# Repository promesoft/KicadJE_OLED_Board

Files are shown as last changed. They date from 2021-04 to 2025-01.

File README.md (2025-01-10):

# KicadJE_OLED_Board
uP Boards that uses I2C SSD1306 for OLED Display faceplate

# Purpose
uProcessor board in eurorack units with an SSD1306 OLED display, two rotary dials/pots, two audio inputs, two cv inputs and two outputs. Must match the Faceplate - KicadJE_OLED_Face.
## Board 1 - ATMega32A
Adjustment:  
2 x Encoder  

CV Input:  
2 x ADC AC/DC couple with optional level adj to match 0-5V ADC

Gate or Input Audio:  
2 x ADC AC/DC couple with optional level adj to match 0-5V ADC

Output CV:  
2 x PWM output through 3 pole active LP  
+-10v

Programming Interface:  
ISP  
Serial  

# Status - Initiated
## Initial 
| Stage  | Detail | Status |
| --- | --- | --- |
| create material  | sch | OK
| | pcb | OK
| | gerber | OK
| production |  |  OK
|  | produced  | OK
|  | delivered | OK
## Preliminary validation
| Test  | Detail | Status |
| --- | --- | --- |
| Initial Inspection | | ok |
| Mechanical Inspection | needs longer pins to OLED | ok |
| Initial Technical Test | Board 1 |  |
| Initial Product Test | Board1 |  |

## Secondary validation
| Test  | Detail | Status |
| --- | --- |--- |
| Product Test | 1 | |
| Quality | 1 | |
| Long Term Product Test |  |  |
| Power Draw |  | 

## Errata
### Errata - 

## Issues and Notes
### 

# Pictures

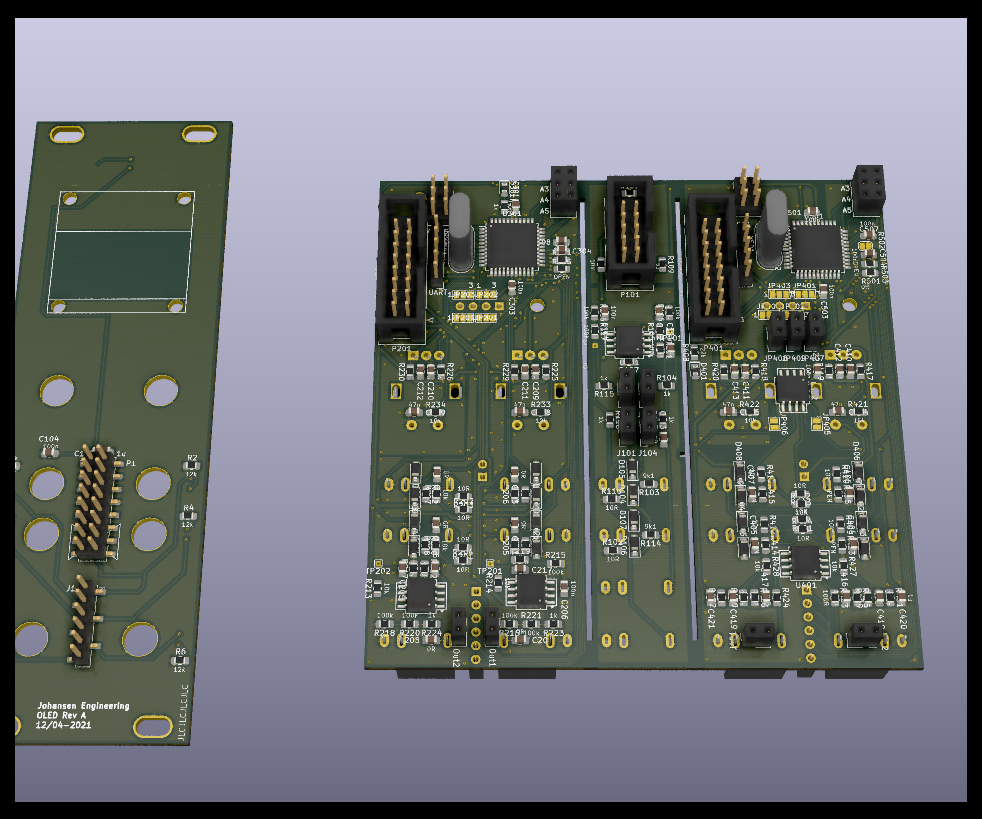
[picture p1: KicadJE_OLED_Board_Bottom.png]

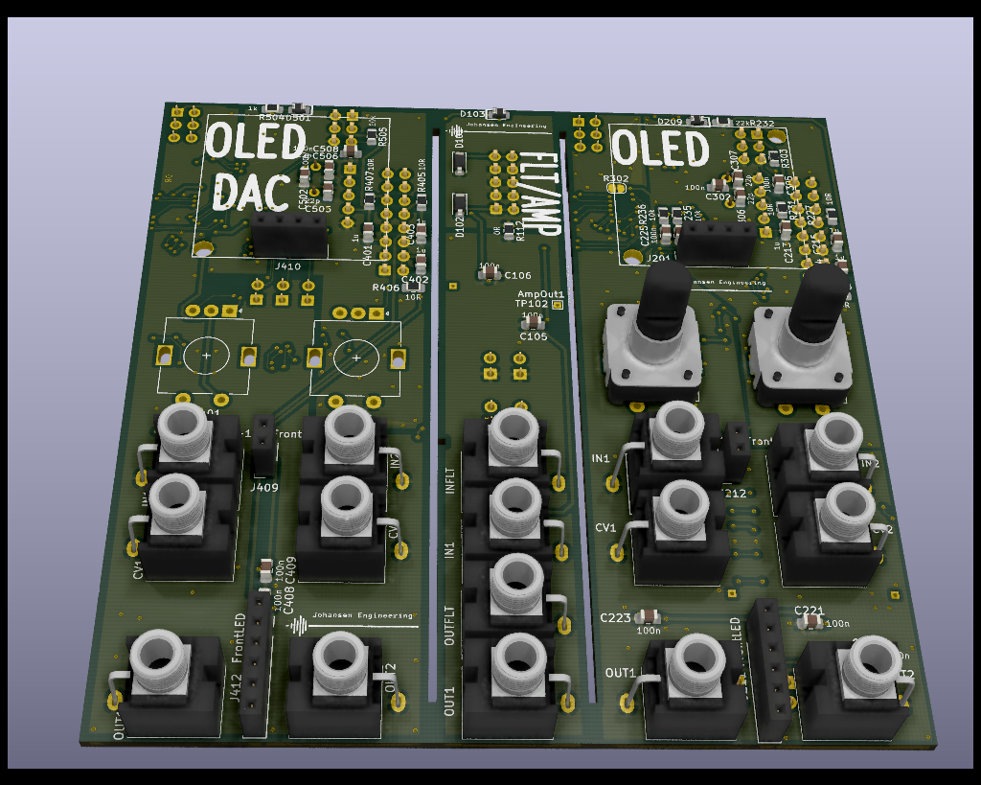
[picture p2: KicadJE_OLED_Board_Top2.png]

# Schematic
## Sch 1
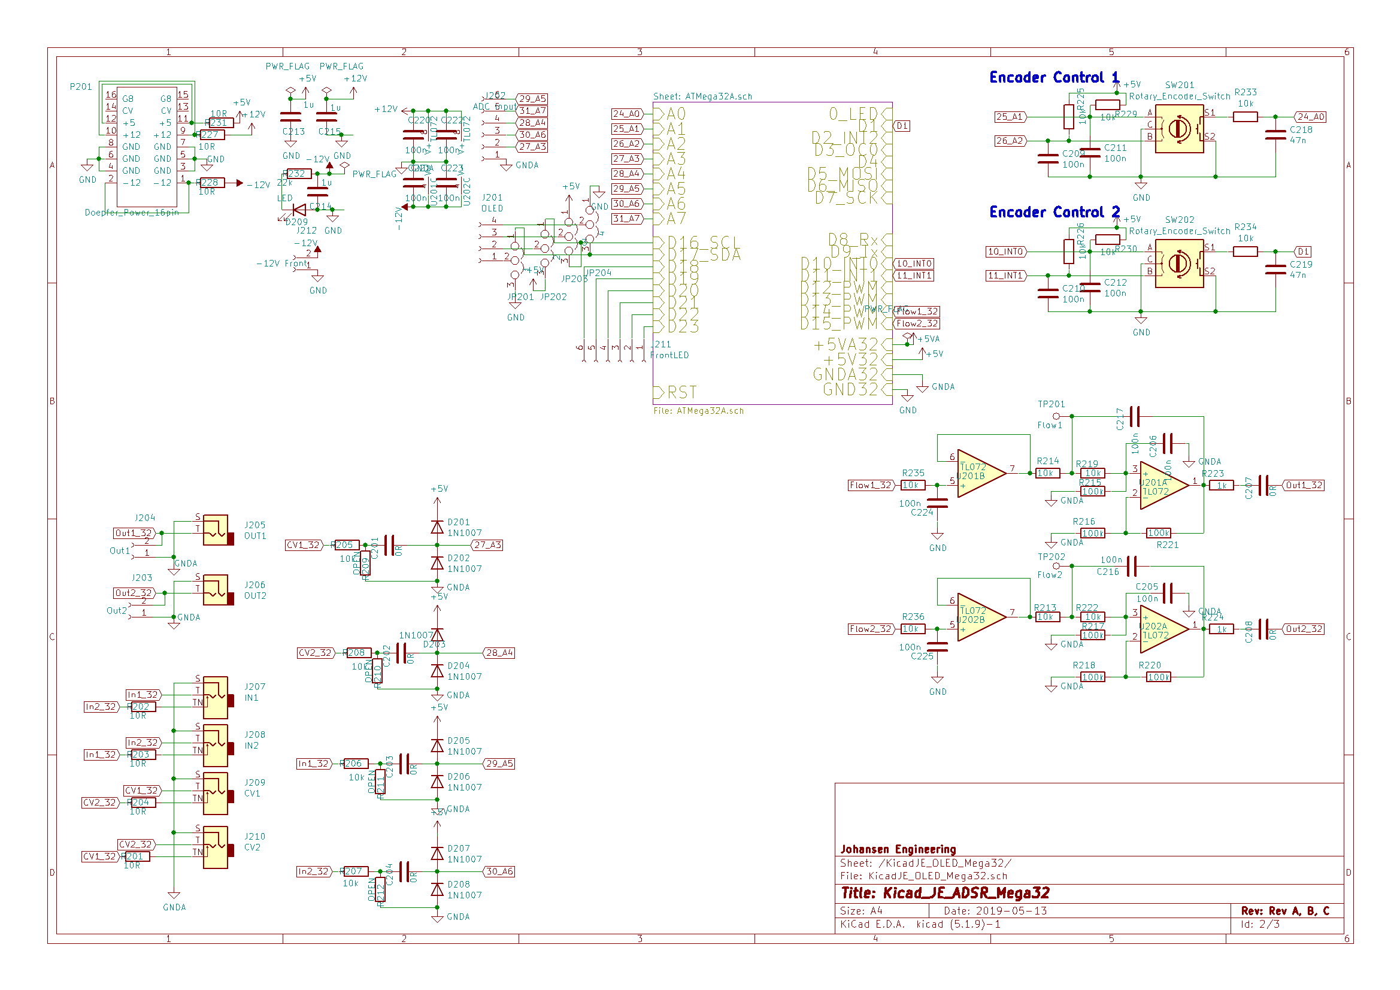
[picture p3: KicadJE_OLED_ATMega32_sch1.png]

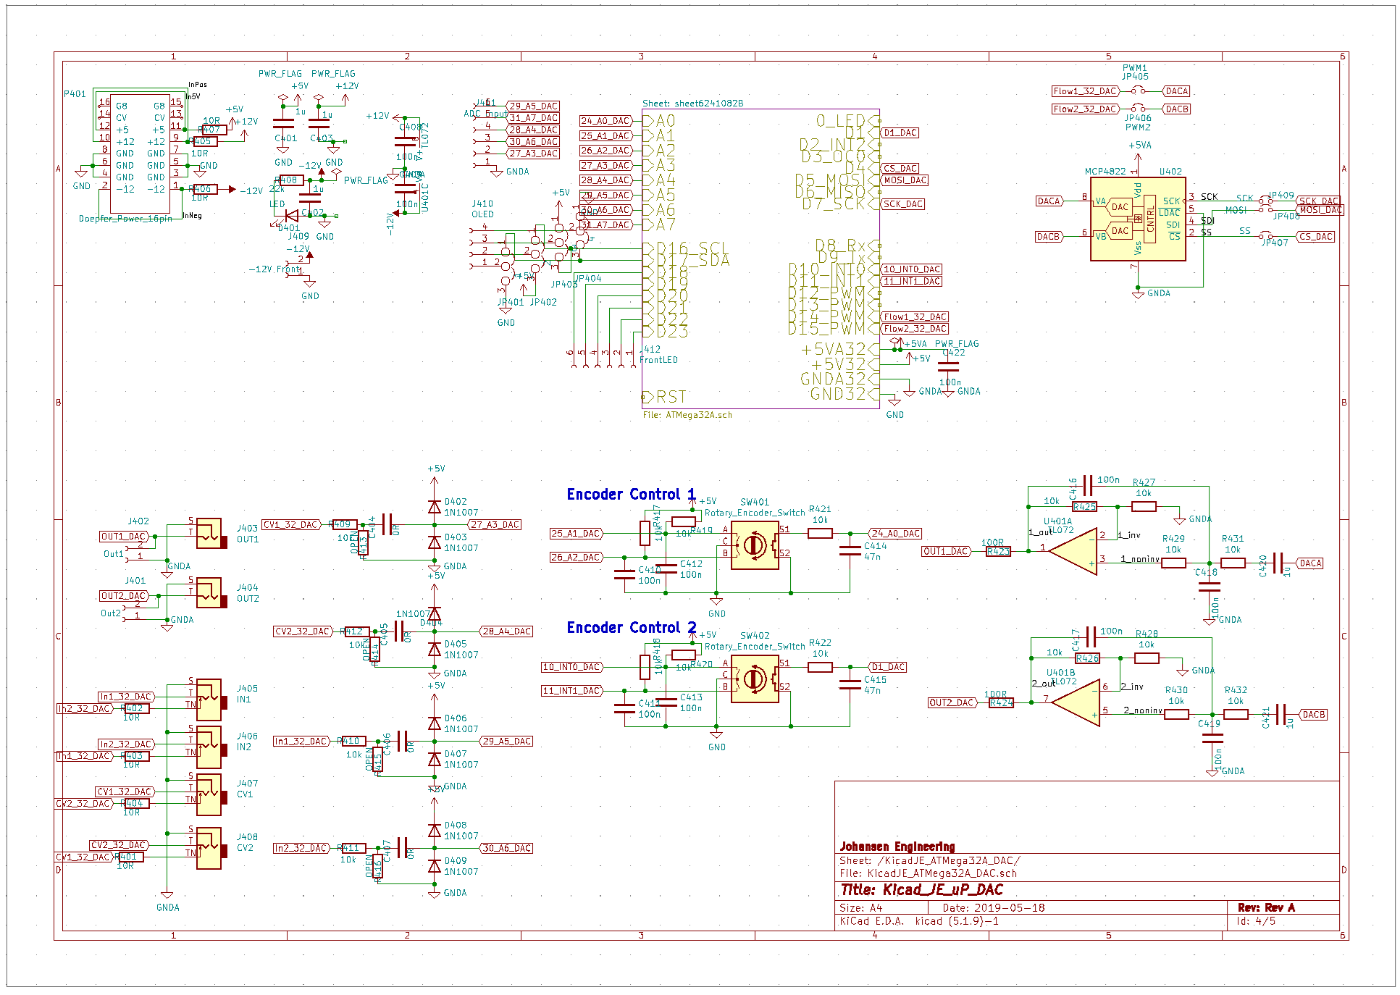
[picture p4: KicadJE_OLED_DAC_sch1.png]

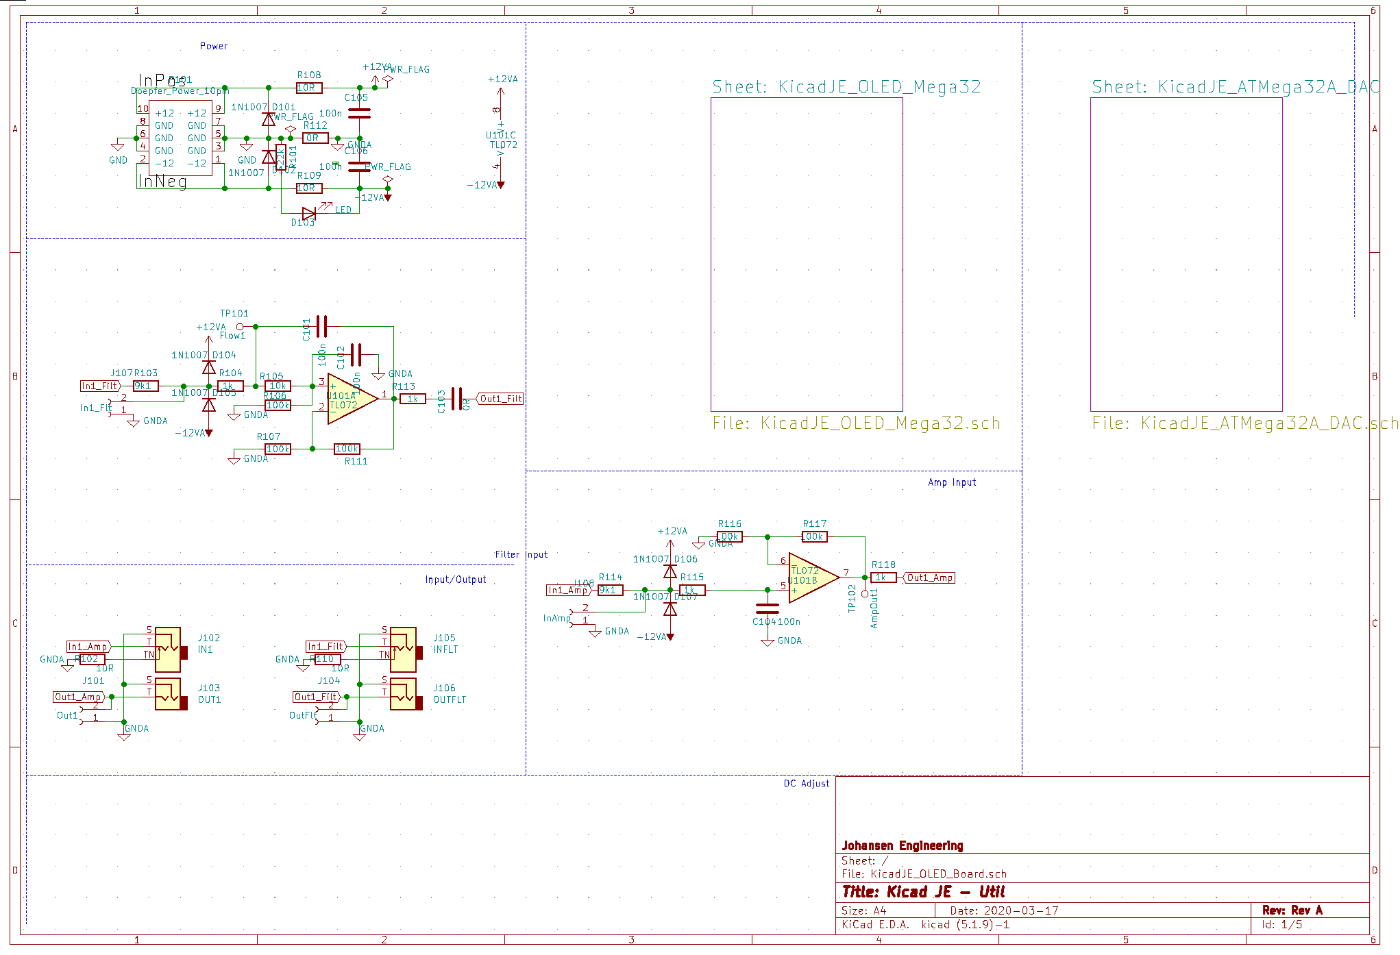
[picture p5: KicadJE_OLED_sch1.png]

#Software
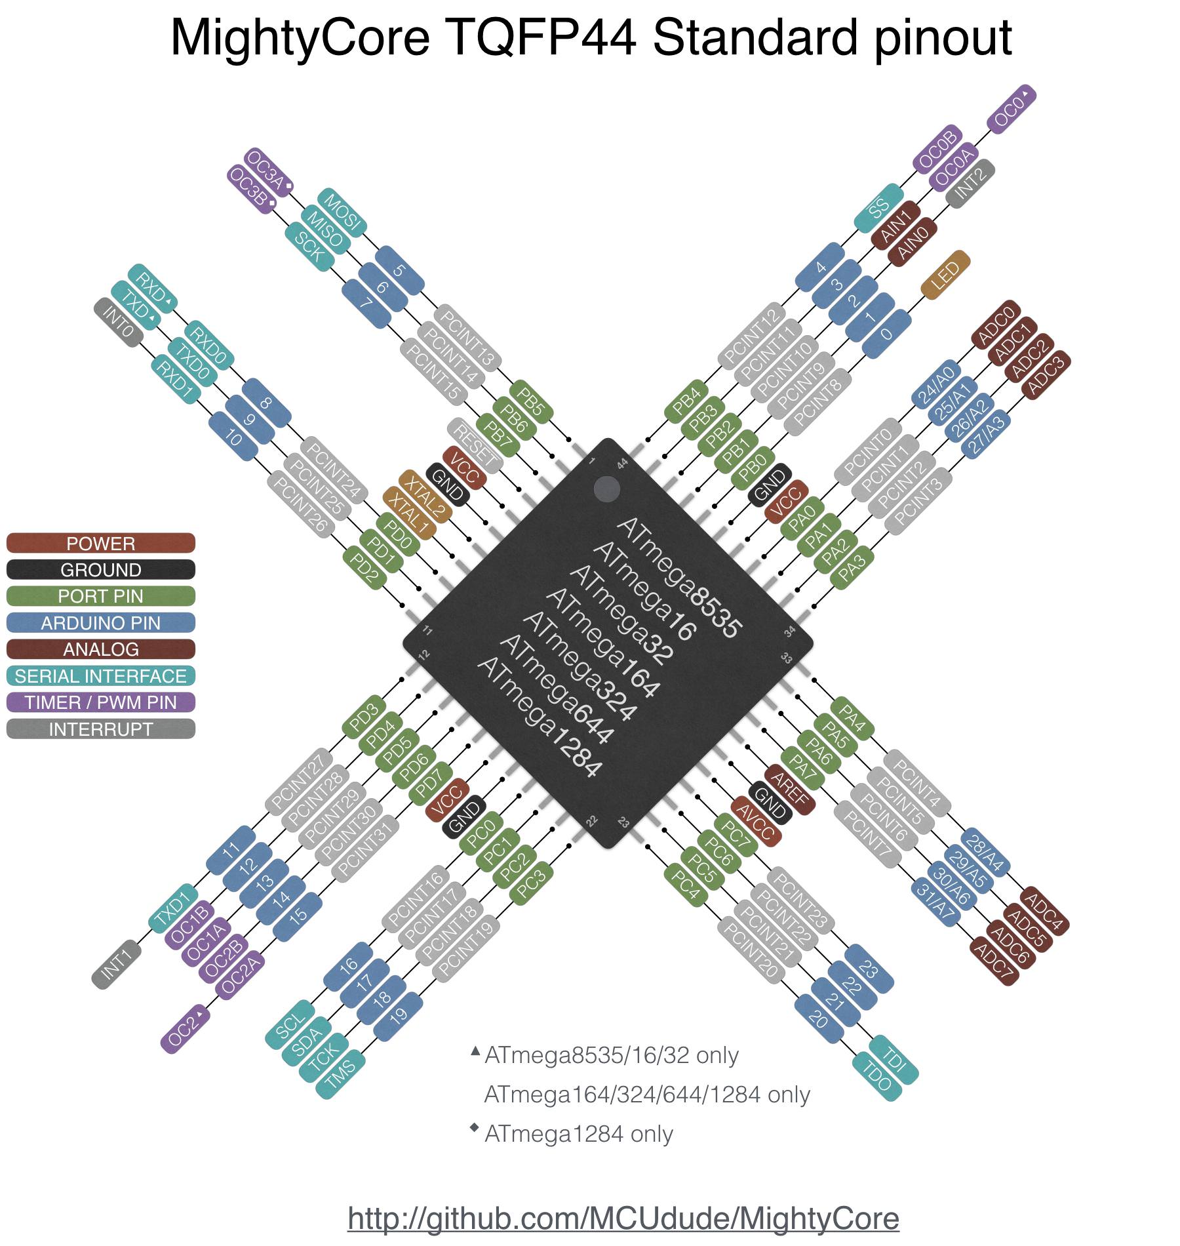
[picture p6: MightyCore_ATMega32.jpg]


# Analysis
## Diag 1


## Prototype


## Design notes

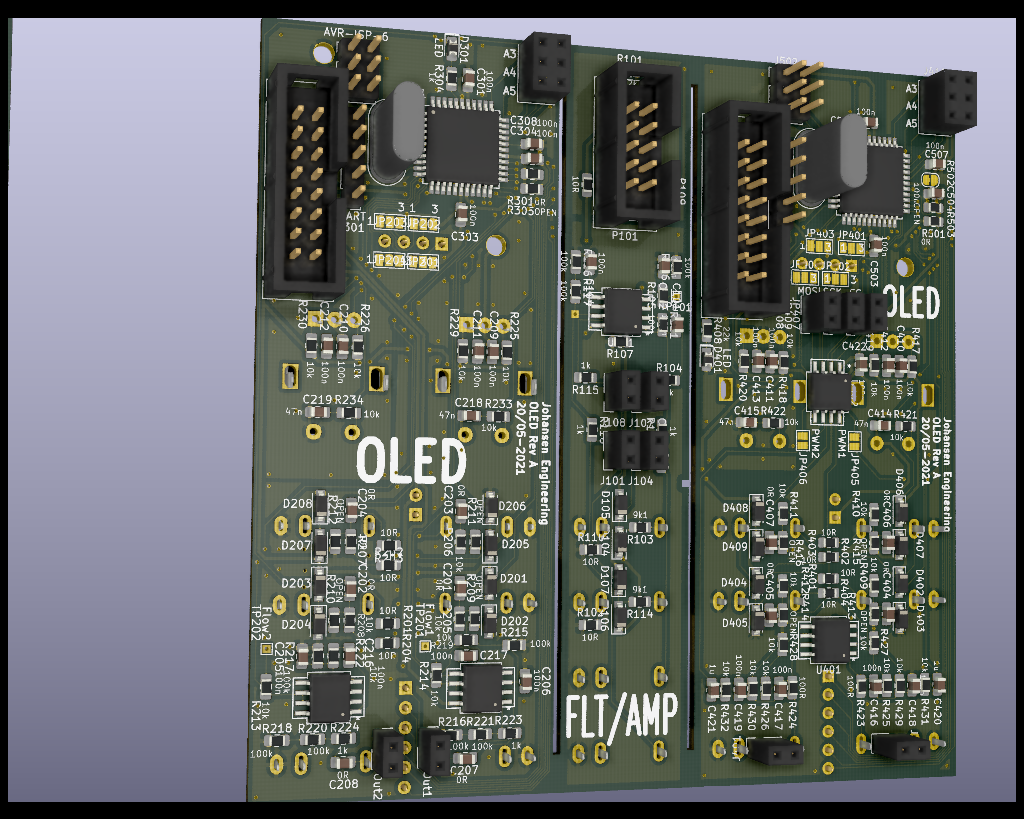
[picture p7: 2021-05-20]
KicadJE_OLED_Board_Bottom1.png

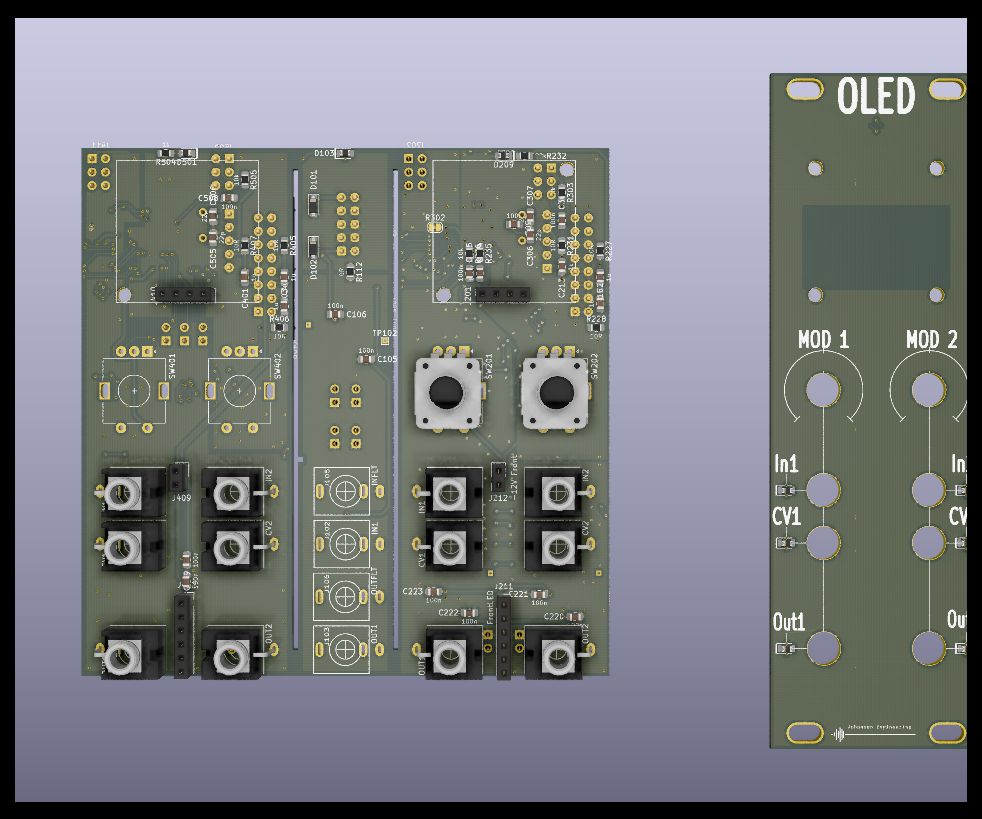
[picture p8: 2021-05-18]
KicadJE_OLED_Board_Top.png

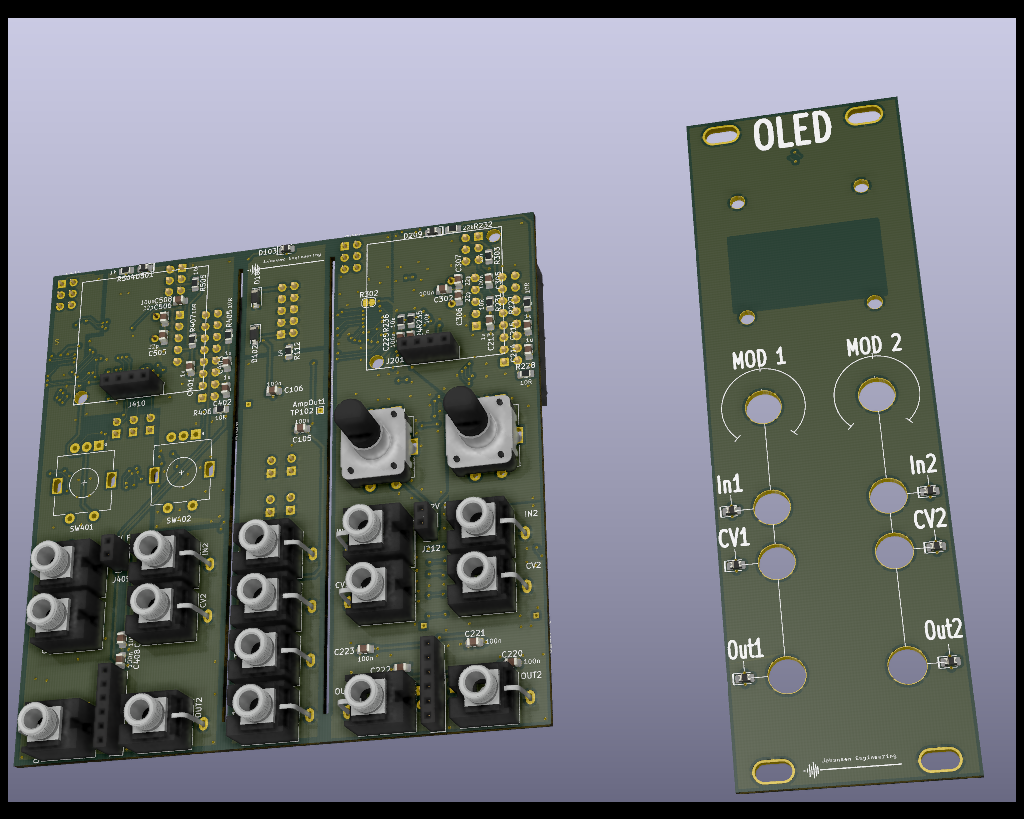
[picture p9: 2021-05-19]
KicadJE_OLED_Board_Top1.png

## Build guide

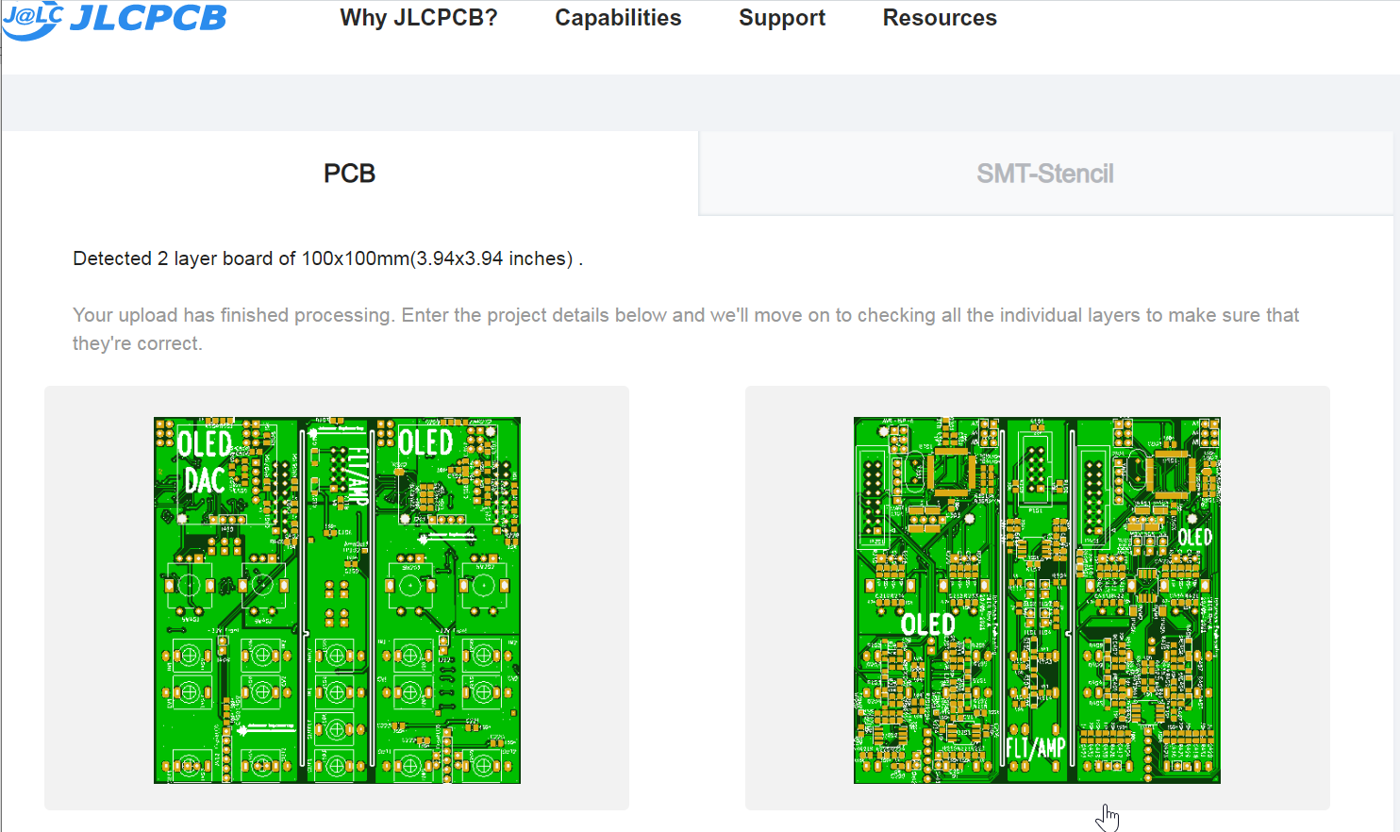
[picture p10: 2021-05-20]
GerberRevA/2021-05-20 23_12_48-PCB Prototype & PCB Fabrication Manufacturer - JLCPCB - Brave.png

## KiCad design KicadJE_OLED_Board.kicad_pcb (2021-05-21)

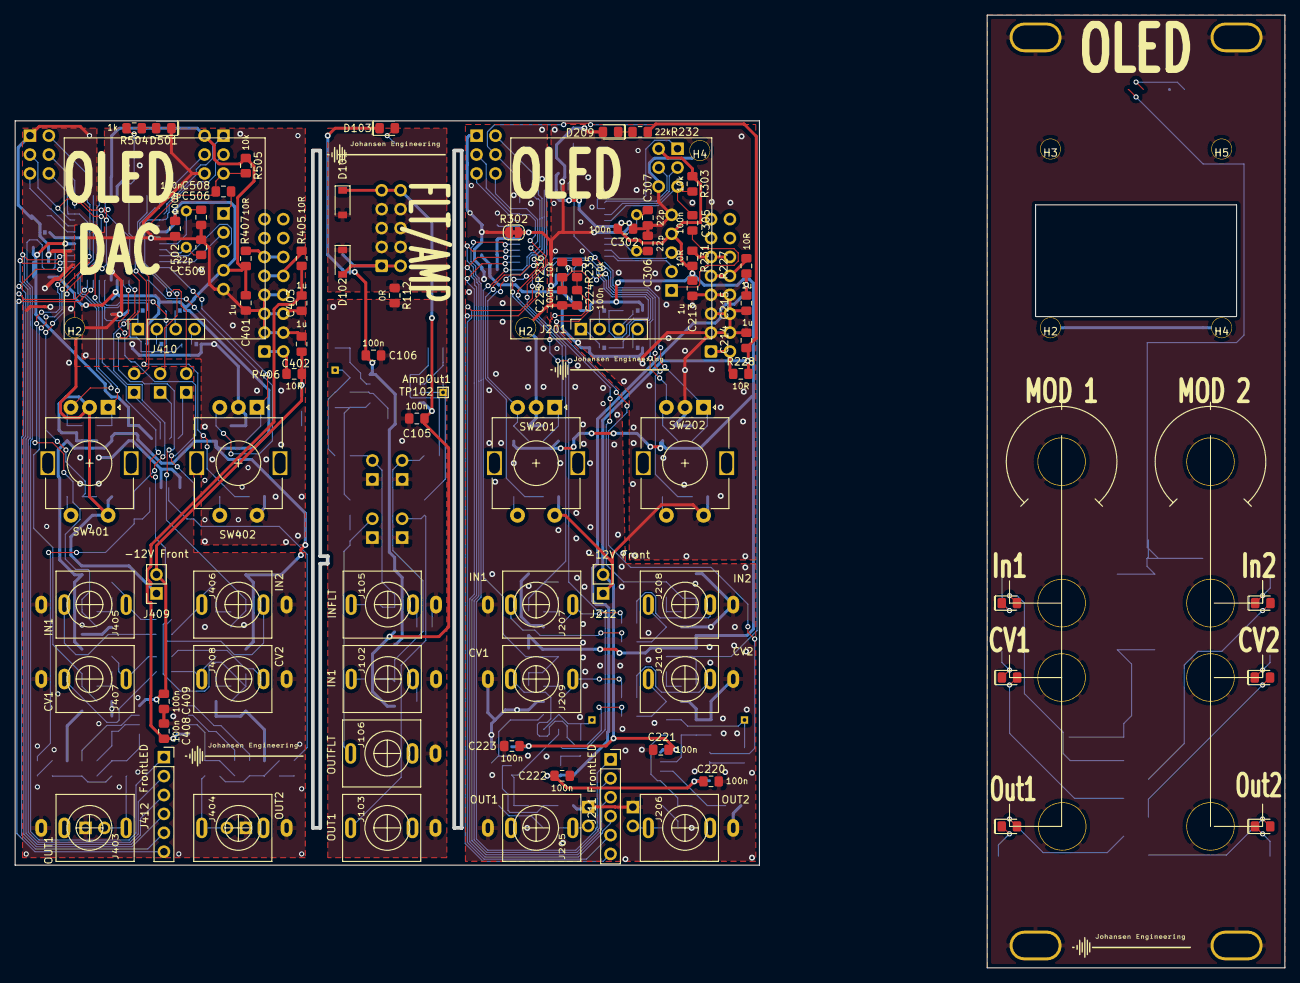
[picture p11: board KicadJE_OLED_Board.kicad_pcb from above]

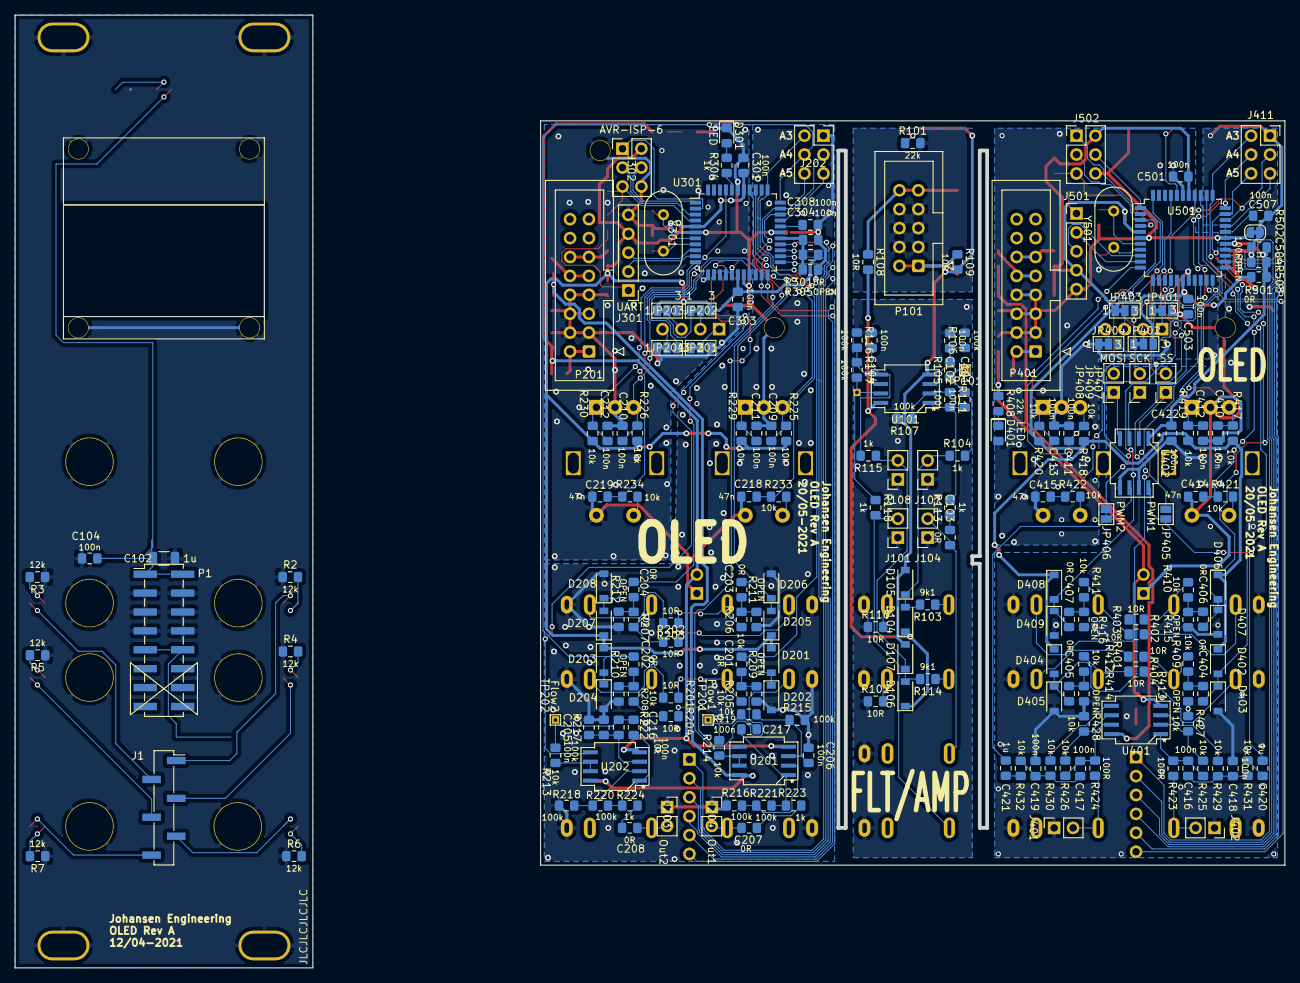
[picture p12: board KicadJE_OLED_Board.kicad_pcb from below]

Board: 2 copper layers, 100.0 x 100.0 mm, 296 parts (203 on the bottom side), 184 nets.

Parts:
C101, C102#2, C104, C104#2, C105, C106, C205, C206, C209, C210, C211, C212, C216, C217, C220, C221, C222, C223, C224, C225, C301, C302, C303, C304, C305, C308, C408, C409, C410, C411, C412, C413, C416, C417, C418, C419, C422, C501, C502, C503, C504, C507, C508: 100n; C_0805_AJ
C102: 1u; C_1206_3216Metric
C103, C201, C202, C203, C204, C207, C208, C404, C405, C406, C407: 0R; C_0805_AJ
C213, C214, C215, C401, C402, C403, C420, C421: 1u; C_0805_AJ
C218, C219, C414, C415: 47n; C_0805_AJ
C306, C307, C505, C506: 22p; C_0805_AJ
D4, D5, D6, D7, D8, D9, D103, D209, D301, D401, D501: LED; D_0805_AJ
D101, D102, D104, D105, D106, D107, D201, D202, D203, D204, D205, D206, D207, D208, D402, D403, D404, D405, D406, D407, D408, D409: 1N1007; D_SOD-123
H2, H2#2, H2#3, H3, H4, H4#2, H5: OLED; M2.7_Plated
H102, H103, H104, H105: MountingHole_Pad; MountingHole_Eurorack3
J1: LED 1-6; PinHeader_1x06_P2.54mm_Vertical_SMD_Pin1Right
J101, J204, J402: Out1; PinSocket_1x02_P2.54mm_Vertical
J102, J207, J405: IN1; PJ301SM
J103, J205, J403: OUT1; PJ301SM
J104: OutFlt; PinSocket_1x02_P2.54mm_Vertical
J105: INFLT; PJ301SM
J106: OUTFLT; PJ301SM
J107: In1_Flt; PinSocket_1x02_P2.54mm_Vertical
J108: InAmp; PinSocket_1x02_P2.54mm_Vertical
J201, J410: OLED; PinSocket_1x04_P2.54mm_Vertical
J202, J411: ADC Input; PinSocket_2x03_P2.54mm_Vertical
J203, J401: Out2; PinSocket_1x02_P2.54mm_Vertical
J206, J404: OUT2; PJ301SM
J208, J406: IN2; PJ301SM
J209, J407: CV1; PJ301SM
J210, J408: CV2; PJ301SM
J211, J412: FrontLED; PinSocket_1x06_P2.54mm_Vertical
J212, J409: -12V Front; PinSocket_1x02_P2.54mm_Vertical
J301, J501: UART; PinHeader_1x05_P2.54mm_Vertical
J302, J502: AVR-ISP-6; PinHeader_2x03_P2.54mm_Vertical
JP201, JP401: 1; SolderJumper-3_P1.3mm_Bridged12_Pad1.0x1.5mm_NumberLabels
JP202, JP402: 2; SolderJumper-3_P1.3mm_Bridged12_Pad1.0x1.5mm_NumberLabels
JP203, JP403: 3; SolderJumper-3_P1.3mm_Bridged12_Pad1.0x1.5mm_NumberLabels
JP204, JP404: 4; SolderJumper-3_P1.3mm_Bridged12_Pad1.0x1.5mm_NumberLabels
JP405: PWM1; SolderJumper-2_P1.3mm_Open_Pad1.0x1.5mm
JP406: PWM2; SolderJumper-2_P1.3mm_Open_Pad1.0x1.5mm
JP407: SS; PinSocket_1x02_P2.54mm_Vertical
JP408: MOSI; PinSocket_1x02_P2.54mm_Vertical
JP409: SCK; PinSocket_1x02_P2.54mm_Vertical
P1: Doepfer_Power_16pin; PinHeader_2x08_P2.54mm_Vertical_SMD
P101: Doepfer_Power_10pin; IDC-Header_2x05_P2.54mm_Vertical
P201, P401: Doepfer_Power_16pin; IDC-Header_2x08_P2.54mm_Vertical
R2, R3, R4, R5, R6, R7: 12k; R_0805_AJ
R101, R232, R408: 22k; R_0805_AJ
R102, R108, R109, R110, R201, R202, R203, R204, R227, R228, R231, R401, R402, R403, R404, R405, R406, R407: 10R; R_0805_AJ
R103, R114: 9k1; R_0805_AJ
R104, R113, R115, R118, R223, R224, R304, R504: 1k; R_0805_AJ
R105, R205, R206, R207, R208, R213, R214, R219, R222, R225, R226, R229, R230, R233, R234, R235, R236, R303, R409, R410, R411, R412, R417, R418, R419, R420, R421, R422, R425, R426, R427, R428, R429, R430, R431, R432, R505: 10k; R_0805_AJ
R106, R107, R111, R116, R117, R215, R216, R217, R218, R220, R221: 100k; R_0805_AJ
R112, R301, R501: 0R; R_0805_AJ
R209, R210, R211, R212, R305, R413, R414, R415, R416, R503: OPEN; R_0805_AJ
R302, R502: 0R; SolderJumper-2_P1.3mm_Bridged_RoundedPad1.0x1.5mm
R423, R424: 100R; R_0805_AJ
SW201, SW202, SW401, SW402: Rotary_Encoder_Switch; RotaryEncoder_Alps_EC11E-Switch_Vertical_H20mm
TP101, TP201: Flow1; TestPoint_THTPad_1.0x1.0mm_Drill0.5mm
TP102: SQ; Jack_6m3
TP102#2: AmpOut1; TestPoint_THTPad_1.0x1.0mm_Drill0.5mm
TP103: In1; Jack_6m3
TP105: In3; Jack_6m3
TP106: HS; Jack_6m3
TP107: OFF1; Pot_6m3_scale1
TP107#2: FM; Jack_6m3
TP108: PWM; Jack_6m3
TP112: Fine; Pot_6m3_scale1
TP202: Flow2; TestPoint_THTPad_1.0x1.0mm_Drill0.5mm
U101, U201, U202, U401: TL072; AJ_SO-8_5.3x6.2mm_P1.27mm
U301, U501: ATmega32A-AU; TQFP-44_10x10mm_P0.8mm
U402: MCP4822; AJ_SO-8_5.3x6.2mm_P1.27mm
Y301, Y501: 16MHz; Crystal_HC49-U_Vertical

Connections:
10_INT0: C212.1, R230.2, SW202.A, U301.11
10_INT0_DAC: C413.1, R420.2, SW402.A, U501.11
11_INT1: C210.1, R226.1, SW202.B, U301.12
11_INT1_DAC: C411.1, R418.1, SW402.B, U501.12
24_A0: C218.1, R233.1, U301.37
24_A0_DAC: C414.1, R421.1, U501.37
25_A1: C211.1, R229.2, SW201.A, U301.36
25_A1_DAC: C412.1, R419.2, SW401.A, U501.36
26_A2: C209.1, R225.1, SW201.B, U301.35
26_A2_DAC: C410.1, R417.1, SW401.B, U501.35
27_A3: C201.2, D201.2, D202.1, J202.2, U301.34
27_A3_DAC: C404.2, D402.2, D403.1, J411.2, U501.34
28_A4: C202.2, D203.2, D204.1, J202.4, U301.33
28_A4_DAC: C405.2, D404.2, D405.1, J411.4, U501.33
29_A5: C203.2, D205.2, D206.1, J202.6, U301.32
29_A5_DAC: C406.2, D406.2, D407.1, J411.6, U501.32
30_A6: C204.2, D207.2, D208.1, J202.3, U301.31
30_A6_DAC: C407.2, D408.2, D409.1, J411.3, U501.31
31_A7: J202.5, U301.30
31_A7_DAC: J411.5, U501.30
+5V: C213.2, C301.2, C302.2, C303.2, C401.2, C501.2, C502.2, C503.2, D201.1, D203.1, D205.1, D207.1, D402.1, D404.1, D406.1, D408.1, J301.4, J302.2, J501.4, J502.2, JP202.3, JP203.1, JP402.3, JP403.1, P1.11, P1.12, R225.2, R226.2, R229.1, R230.1, R231.2, R301.2, R303.1, R407.2, R417.2, R418.2, R419.1, R420.1, R501.2, R505.1, U301.5, U301.17, U301.38, U501.5, U501.17, U501.38
+5VA: C304.2, C422.1, C504.2, R301.1, R305.1, R501.1, R503.1, U301.27, U402.1, U501.27
+12V: C215.2, C220.1, C222.1, C403.2, C408.1, R227.2, R405.2, U201.8, U202.8, U401.8
+12VA: C105.1, D104.1, D106.1, P1.9, P1.10, R108.2, U101.8
-12V: C214.2, C221.2, C223.2, C402.2, C409.2, J212.2, J409.2, R228.2, R232.2, R406.2, R408.2, U201.4, U202.4, U401.4
-12VA: C102.2, C104.2, C106.2, D103.1, D105.2, D107.2, P1.1, P1.2, R109.2, U101.4
/InNeg: D102.2, P101.1, P101.2, R109.1
/InPos: D101.1, P101.9, P101.10, R108.1
/KicadJE_ATMega32A_DAC/1_inv: R425.1, R427.2, U401.2
/KicadJE_ATMega32A_DAC/1_noninv: R429.2, U401.3
/KicadJE_ATMega32A_DAC/1_out: C416.1, R423.1, R425.2, U401.1
/KicadJE_ATMega32A_DAC/2_inv: R426.1, R428.2, U401.6
/KicadJE_ATMega32A_DAC/2_noninv: R430.2, U401.5
/KicadJE_ATMega32A_DAC/2_out: C417.1, R424.1, R426.2, U401.7
/KicadJE_ATMega32A_DAC/In5V: P401.11, P401.12, R407.1
/KicadJE_ATMega32A_DAC/InNeg: P401.1, P401.2, R406.1
/KicadJE_ATMega32A_DAC/InPos: P401.9, P401.10, R405.1
/KicadJE_ATMega32A_DAC/SCK: JP409.1, U402.3
/KicadJE_ATMega32A_DAC/SDI: JP408.1, U402.4
/KicadJE_ATMega32A_DAC/SS: JP407.1, U402.2
/KicadJE_ATMega32A_DAC/sheet6241082B/0_LED: R504.2, U501.40
/KicadJE_ATMega32A_DAC/sheet6241082B/D6_MISO: J502.1, U501.2
/KicadJE_ATMega32A_DAC/sheet6241082B/D8_Rx: J501.3, U501.9
/KicadJE_ATMega32A_DAC/sheet6241082B/D9_Tx: J501.2, U501.10
/KicadJE_ATMega32A_DAC/sheet6241082B/D16_SCL: JP402.1, JP403.3, U501.19
/KicadJE_ATMega32A_DAC/sheet6241082B/D17_SDA: JP401.1, JP404.3, U501.20
/KicadJE_ATMega32A_DAC/sheet6241082B/D18: J412.6, U501.21
/KicadJE_ATMega32A_DAC/sheet6241082B/D19: J412.5, U501.22
/KicadJE_ATMega32A_DAC/sheet6241082B/D20: J412.4, U501.23
/KicadJE_ATMega32A_DAC/sheet6241082B/D21: J412.3, U501.24
/KicadJE_ATMega32A_DAC/sheet6241082B/D22: J412.2, U501.25
/KicadJE_ATMega32A_DAC/sheet6241082B/D23: J412.1, U501.26
/KicadJE_OLED_Mega32/ATMega32A.sch/0_LED: R304.2, U301.40
/KicadJE_OLED_Mega32/ATMega32A.sch/D5_MOSI: J302.4, U301.1
/KicadJE_OLED_Mega32/ATMega32A.sch/D6_MISO: J302.1, U301.2
/KicadJE_OLED_Mega32/ATMega32A.sch/D7_SCK: J302.3, U301.3
/KicadJE_OLED_Mega32/ATMega32A.sch/D8_Rx: J301.3, U301.9
/KicadJE_OLED_Mega32/ATMega32A.sch/D9_Tx: J301.2, U301.10
/KicadJE_OLED_Mega32/ATMega32A.sch/D16_SCL: JP202.1, JP203.3, U301.19
/KicadJE_OLED_Mega32/ATMega32A.sch/D17_SDA: JP201.1, JP204.3, U301.20
/KicadJE_OLED_Mega32/ATMega32A.sch/D18: J211.6, U301.21
/KicadJE_OLED_Mega32/ATMega32A.sch/D19: J211.5, U301.22
/KicadJE_OLED_Mega32/ATMega32A.sch/D20: J211.4, U301.23
/KicadJE_OLED_Mega32/ATMega32A.sch/D21: J211.3, U301.24
/KicadJE_OLED_Mega32/ATMega32A.sch/D22: J211.2, U301.25
/KicadJE_OLED_Mega32/ATMega32A.sch/D23: J211.1, U301.26
/KicadJE_OLED_Mega32/In5V: P201.11, P201.12, R231.1
/KicadJE_OLED_Mega32/InNeg: P201.1, P201.2, R228.1
/KicadJE_OLED_Mega32/InPos: P201.9, P201.10, R227.1
CS_DAC: JP407.2, U501.44
CV1_32: J209.T, R201.1, R205.1
CV1_32_DAC: J407.T, R401.1, R409.1
CV2_32: J210.T, R204.1, R208.1
CV2_32_DAC: J408.T, R404.1, R412.1
D1: C219.1, R234.1, U301.41
D1_DAC: C415.1, R422.1, U501.41
DACA: C420.2, JP405.2, U402.8
DACB: C421.2, JP406.2, U402.6
Flow1_32: R235.1, U301.15
Flow1_32_DAC: JP405.1, U501.15
Flow2_32: R236.1, U301.16
Flow2_32_DAC: JP406.1, U501.16
GND: C102.1, C104.1, C209.2, C210.2, C211.2, C212.2, C213.1, C214.1, C215.1, C218.2, C219.2, C224.2, C225.2, C301.1, C302.1, C303.1, C306.2, C307.2, C401.1, C402.1, C403.1, C410.2, C411.2, C412.2, C413.2, C414.2, C415.2, C501.1, C502.1, C503.1, C505.2, C506.2, D101.2, D102.1, D209.2, D301.1, D401.2, D501.1, H2.1, H2#2.1, H2#3.1, H3.1, H4.1, H4#2.1, H5.1, H102.1, H103.1, H104.1, H105.1, J212.1, J301.5, J302.6, J409.1, J501.5, J502.6, JP201.3, JP204.1, JP401.3, JP404.1, P1.3, P1.4, P1.5, P1.6, P1.7, P1.8, P101.3, P101.4, P101.5, P101.6, P101.7, P101.8, P201.3, P201.4, P201.5, P201.6, P201.7, P201.8, P401.3, P401.4, P401.5, P401.6, P401.7, P401.8, R2.1, R3.1, R4.1, R5.1, R6.1, R7.1, R101.2, R112.1, R302.2, R502.2, SW201.C, SW201.S2, SW202.C, SW202.S2, SW401.C, SW401.S2, SW402.C, SW402.S2, TP102.1, TP103.1, TP105.1, TP106.1, TP107.1, TP107#2.1, TP108.1, TP112.1, U301.6, U301.18, U301.28, U301.39, U501.6, U501.18, U501.28, U501.39
GNDA: C102#2.2, C104#2.2, C105.2, C106.1, C205.2, C206.2, C220.2, C221.1, C222.2, C223.1, C304.1, C308.2, C408.2, C409.1, C418.2, C419.2, C422.2, C504.1, C507.2, D202.2, D204.2, D206.2, D208.2, D403.2, D405.2, D407.2, D409.2, J101.1, J102.S, J103.S, J104.1, J105.S, J106.S, J107.1, J108.1, J202.1, J203.1, J204.1, J205.S, J206.S, J207.S, J208.S, J209.S, J210.S, J401.1, J402.1, J403.S, J404.S, J405.S, J406.S, J407.S, J408.S, J411.1, R102.1, R106.2, R107.2, R110.1, R112.2, R116.1, R209.2, R210.2, R211.2, R212.2, R215.2, R216.2, R217.2, R218.2, R302.1, R305.2, R413.2, R414.2, R415.2, R416.2, R427.1, R428.1, R502.1, R503.2, U402.5, U402.7
In1_32: J207.T, R203.1, R206.1
In1_32_DAC: J405.T, R403.1, R410.1
In1_Amp: J102.T, R114.1
In1_Filt: J105.T, R103.1
In2_32: J208.T, R202.1, R207.1
In2_32_DAC: J406.T, R402.1, R411.1
MOSI_DAC: J502.4, JP408.2, U501.1
unnamed: C101.1, R104.2, R105.1, TP101.1
unnamed: C101.2, R111.2, R113.2, U101.1
unnamed: C102#2.1, R105.2, R106.1, U101.3
unnamed: C103.1, R113.1
unnamed: C104#2.1, R115.2, U101.5
unnamed: C201.1, R205.2, R209.1
unnamed: C202.1, R208.2, R210.1
unnamed: C203.1, R206.2, R211.1
unnamed: C204.1, R207.2, R212.1
unnamed: C205.1, R217.1, R222.2, U202.3
unnamed: C206.1, R215.1, R219.2, U201.3
unnamed: C207.1, R223.1
unnamed: C208.1, R224.1
unnamed: C216.1, R213.2, R222.1, TP202.1
unnamed: C216.2, R220.1, R224.2, U202.1
unnamed: C217.1, R214.2, R219.1, TP201.1
unnamed: C217.2, R221.2, R223.2, U201.1
unnamed: C224.1, R235.2, U201.5
unnamed: C225.1, R236.2, U202.5
unnamed: C305.2, J301.1
unnamed: C306.1, U301.8, Y301.1
unnamed: C307.1, U301.7, Y301.2
unnamed: C308.1, U301.29
unnamed: C404.1, R409.2, R413.1
unnamed: C405.1, R412.2, R414.1
unnamed: C406.1, R410.2, R415.1
unnamed: C407.1, R411.2, R416.1
unnamed: C416.2, C418.1, R429.1, R431.2
unnamed: C417.2, C419.1, R430.1, R432.2
unnamed: C420.1, R431.1
unnamed: C421.1, R432.1
unnamed: C505.1, U501.8, Y501.1
unnamed: C506.1, U501.7, Y501.2
unnamed: C507.1, U501.29
unnamed: C508.2, J501.1
unnamed: D4.1, R2.2
unnamed: D4.2, J1.1
unnamed: D5.1, R3.2
unnamed: D5.2, J1.2
unnamed: D6.1, R4.2
unnamed: D6.2, J1.3
unnamed: D7.1, R5.2
unnamed: D7.2, J1.4
unnamed: D8.1, R6.2
unnamed: D8.2, J1.5
unnamed: D9.1, R7.2
unnamed: D9.2, J1.6
unnamed: D103.2, R101.1
unnamed: D104.2, D105.1, J107.2, R103.2, R104.1
unnamed: D106.2, D107.1, J108.2, R114.2, R115.1
unnamed: D209.1, R232.1
unnamed: D301.2, R304.1
unnamed: D401.1, R408.1
unnamed: D501.2, R504.1
unnamed: J102.TN, R102.2
unnamed: J105.TN, R110.2
unnamed: J201.1, JP201.2
unnamed: J201.2, JP202.2
unnamed: J201.3, JP203.2
unnamed: J201.4, JP204.2
unnamed: J207.TN, R202.2
unnamed: J208.TN, R203.2
unnamed: J209.TN, R204.2
unnamed: J210.TN, R201.2
unnamed: J405.TN, R402.2
unnamed: J406.TN, R403.2
unnamed: J407.TN, R404.2
unnamed: J408.TN, R401.2
unnamed: J410.1, JP401.2
unnamed: J410.2, JP402.2
unnamed: J410.3, JP403.2
unnamed: J410.4, JP404.2
unnamed: P1.13, P1.14
unnamed: P1.15, P1.16
unnamed: R107.1, R111.1, U101.2
unnamed: R116.2, R117.1, U101.6
unnamed: R117.2, R118.1, TP102#2.1, U101.7
unnamed: R213.1, U202.6, U202.7
unnamed: R214.1, U201.6, U201.7
unnamed: R216.1, R221.1, U201.2
unnamed: R218.1, R220.2, U202.2
unnamed: R233.2, SW201.S1
unnamed: R234.2, SW202.S1
unnamed: R421.2, SW401.S1
unnamed: R422.2, SW402.S1
OUT1_DAC: J402.2, J403.T, R423.2
OUT2_DAC: J401.2, J404.T, R424.2
Out1_32: C207.2, J204.2, J205.T
Out1_Amp: J101.2, J103.T, R118.2
Out1_Filt: C103.2, J104.2, J106.T
Out2_32: C208.2, J203.2, J206.T
SCK_DAC: J502.3, JP409.2, U501.3
reset: C305.1, C508.1, J302.5, J502.5, R303.2, R505.2, U301.4, U501.4

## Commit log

2021-04-30 Changing source of PCB template
    [ATMega32A.kicad_pcb, KicadJE_Face.kicad_pcb]
2021-04-30 Updating Atmega32A subboard
    [ATMega32A.kicad_pcb, ATMega32A.sch, KicadJE_ADSR_Mega32.sch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]
2021-04-30 Placing hierarchical labels on ATMega32A
    [ATMega32A.sch, KicadJE_ADSR_Mega32.sch]
2021-04-30 Subboard done
    [ATMega32A.sch, KicadJE_ADSR_Mega32.sch]
2021-04-30 Aref resolved - OLED in sch
    [KicadJE_ADSR_Mega32.sch]
2021-04-30 Front LED
    [ATMega32A.sch, KicadJE_ADSR_Mega32.sch]
2021-04-30 Cleanup MasterSCH
    [ATMega32A.sch, KicadJE_ADSR_Mega32.sch, KicadJE_OLED_Board.sch]
2021-04-30 Importing Encoder from Midi2CV
    [ATMega32A.sch, Kicad-Midi2CV2.sch, KicadJE_ADSR_Mega32.sch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]
2021-05-01 In/CV+Encoder matched to analog input
    [ATMega32A.sch, KicadJE_ADSR_Mega32.sch, KicadJE_OLED_Board.sch]
2021-05-04 5VA on Atmega32A
    [ATMega32A.sch, KicadJE_ADSR_Mega32.sch, KicadJE_OLED_Board.sch]
2021-05-04 Initial footprints and netlist
    [ATMega32A.sch, KicadJE_ADSR_Mega32.sch, KicadJE_OLED_Board.sch]
2021-05-04 PCB outline
    [KicadJE_OLED_Board.kicad_pcb]
2021-05-04 Footprint upd
    [KicadJE_ADSR_Mega32.sch, KicadJE_OLED_Board.sch]
2021-05-04 Encoder 2
    [ATMega32A.sch, KicadJE_ADSR_Mega32.sch, KicadJE_OLED_Board.kicad_pcb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]
2021-05-04 Component place
    [KicadJE_OLED_Board.kicad_pcb]
2021-05-04 cleanup and rename sch subs
    [ATMega32A.sch, Kicad-Midi2CV2.sch, KicadJE_ADSR_Mega32.sch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]
2021-05-04 Most components placed
    [ATMega32A.sch, KicadJE_OLED_Board.kicad_pcb, KicadJE_OLED_Mega32.sch]
2021-05-04 Sallen Key LP filter added to output
    [KicadJE_OLED_Mega32.sch]
2021-05-04 6pin input hdr
    [KicadJE_OLED_Mega32.sch]
2021-05-04 Added buffer for output
    [KicadJE_OLED_Mega32.sch]
2021-05-04 Components placed for KicadJE_OLED_Mega32
    [KicadJE_OLED_Board.kicad_pcb, KicadJE_OLED_Mega32.sch]
2021-05-06 Small Amp/Filter circuit
    [KicadJE_OLED_Board.sch]
2021-05-07 Filt/Amp Netlist
    [KicadJE_OLED_Board.kicad_pcb, KicadJE_OLED_Board.sch]
2021-05-09 move pinhdr from in jacks to input circuit
    after protection resistor - so pcb may be cut above the connectors in case this is needed
    [KicadJE_OLED_Board.kicad_pcb, KicadJE_OLED_Board.sch]
2021-05-09 placed amp/filt
    [KicadJE_OLED_Board.kicad_pcb, KicadJE_OLED_Board.sch]
2021-05-10 Sheet 2 - ATMega32A DAC
    [ATMega32A.sch, KicadJE_ATMega32A_DAC.sch, KicadJE_OLED_Board.sch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]
2021-05-10 annotate dac
    [ATMega32A.sch, KicadJE_ATMega32A_DAC.sch]
2021-05-10 footprints dac
    [ATMega32A.sch, KicadJE_ATMega32A_DAC.sch]
2021-05-10 Placing DAC
    [KicadJE_OLED_Board.kicad_pcb]
2021-05-11 Components placed
    [KicadJE_ATMega32A_DAC.sch, KicadJE_OLED_Board.kicad_pcb]
2021-05-14 Power Amp/FLT
    [KicadJE_OLED_Board.kicad_pcb]
2021-05-16 Wiring DAC board - initiated
    [KicadJE_ATMega32A_DAC.sch, KicadJE_OLED_Board.kicad_pcb, KicadJE_OLED_Board.sch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]
2021-05-16 Initial DAC layout
    [KicadJE_OLED_Board.kicad_pcb]
2021-05-18 Update KicadJE_OLED_Board.kicad_pcb
    All boards routed initially
    [KicadJE_OLED_Board.kicad_pcb]
2021-05-18 DRC
    DRC
    [KicadJE_OLED_Board.kicad_pcb]
2021-05-18 D1 -> D1_DAC
    [ATMega32A.sch, KicadJE_ATMega32A_DAC.sch]
2021-05-18 Update KicadJE_OLED_Board.kicad_pcb
    D1__Dac on PCB
    [KicadJE_OLED_Board.kicad_pcb]
2021-05-18 Pictures of the board before label adj
2021-05-19 Front Labels
    [KicadJE_OLED_Board.kicad_pcb]
2021-05-19 3D Amp
    [KicadJE_OLED_Board.kicad_pcb]
2021-05-20 Update KicadJE_OLED_Board.kicad_pcb
    Starting to label back
    [KicadJE_OLED_Board.kicad_pcb]
2021-05-20 Update KicadJE_OLED_Board.kicad_pcb
    DAC Labeled bottom
    [KicadJE_OLED_Board.kicad_pcb]
2021-05-20 Update KicadJE_OLED_Board.kicad_pcb
    Logo
    [KicadJE_OLED_Board.kicad_pcb]
2021-05-20 Update KicadJE_OLED_Board.kicad_pcb
    Labels
    [KicadJE_OLED_Board.kicad_pcb]
2021-05-20 Update KicadJE_OLED_Board.kicad_pcb
    Labels done
    [KicadJE_OLED_Board.kicad_pcb]
2021-05-20 DRC done
    [KicadJE_OLED_Board.kicad_pcb]
2021-05-20 Create 2021-05-20 23_12_48-PCB Prototype & PCB Fabrication Manufacturer - JLCPCB - Brave.png
